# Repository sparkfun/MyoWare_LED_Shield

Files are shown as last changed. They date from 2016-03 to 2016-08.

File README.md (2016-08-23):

MyoWare™ LED Shield
========================================

MyoWare™ LED Shield

[*MyoWare LED Shield (13688)*](https://www.sparkfun.com/products/13688)

The MyoWare™ LED Shield is designed to pair with the MyoWare™ Muscle Sensor. The 10 segment bar graph shows the magnitude of the measured signal.

Repository Contents
-------------------

* **/Hardware** - Eagle design files (.brd, .sch)

Documentation
--------------
* **[Hookup Guide](https://learn.sparkfun.com/tutorials/myoware-muscle-sensor-kit?_ga=1.172011619.1515819426.1457626448)** - Basic hookup guide for the MyoWare™ LED Shield.
* **[SparkFun Fritzing repo](https://github.com/sparkfun/Fritzing_Parts)** - Fritzing diagrams for SparkFun products.
* **[SparkFun 3D Model repo](https://github.com/sparkfun/3D_Models)** - 3D models of SparkFun products.

License Information
-------------------

This product is _**open source**_!

Please review the LICENSE.md file for license information.

If you have any questions or concerns on licensing, please contact techsupport@sparkfun.com.

Distributed as-is; no warranty is given.

- Your friends at SparkFun.

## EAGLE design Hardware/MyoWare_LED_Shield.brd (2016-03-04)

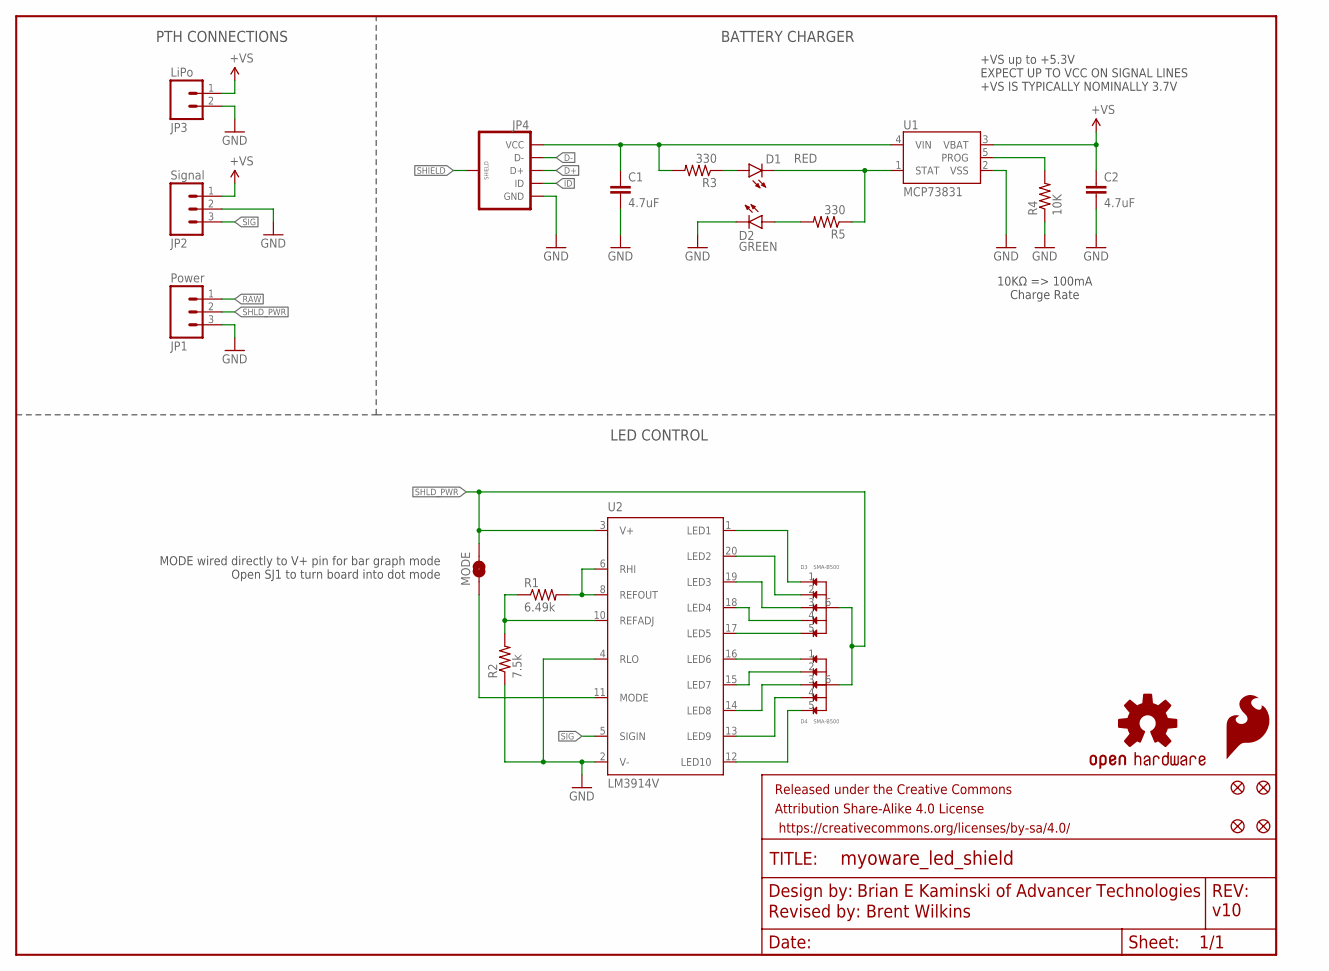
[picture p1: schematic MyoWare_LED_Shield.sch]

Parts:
C1, C2: 4.7uF; 0603-CAP
D1: RED; LED-0603
D2: GREEN; LED-0603
D3, D4: SMA-B500; LED_BAR_SMD
FID1, FID2, FID3, FID4: FIDUCIAL1X2; FIDUCIAL-1X2
FRAME1: FRAME-LETTER; CREATIVE_COMMONS
JP1: Power; 1X03_NO_SILK
JP2: Signal; 1X03_NO_SILK
JP3: LiPo; 1X02_NO_SILK
JP4: USB_MICROB_PLUGCONN-11752; USB-B-MICRO-SMD_V03
LOGO1: SFE_LOGO_FLAME.1_INCH; SFE_LOGO_FLAME_.1
LOGO2: OSHW-LOGOS; OSHW-LOGO-S
MODE: JUMPER-PAD-2-NC_BY_TRACE; PAD-JUMPER-2-NC_BY_TRACE_YES_SILK
R1: 6.49k; R0603
R2: 7.5k; R0603
R3, R5: 330; 0603-RES
R4: 10K; 0603-RES
U1: MCP73831; SOT23-5
U2: LM3914V; PLCC20S

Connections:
+VS: C2.1, JP2.1, JP3.1, U1.3 (VBAT)
D+: JP4.D+
D-: JP4.D-
GND: C1.2, C2.2, D2.C, JP1.3, JP2.2, JP3.2, JP4.GND, R2.1, R4.1, U1.2 (VSS), U2.2 (V-), U2.4 (RLO)
ID: JP4.ID
unnamed: D3.1, U2.1 (LED1)
unnamed: D3.2, U2.20 (LED2)
unnamed: D3.5, U2.17 (LED5)
unnamed: D3.3, U2.19 (LED3)
unnamed: D4.1, U2.16 (LED6)
unnamed: MODE.1, U2.11 (MODE)
unnamed: D3.4, U2.18 (LED4)
unnamed: D2.A, R5.2
unnamed: D1.A, R3.1
unnamed: D4.2, U2.15 (LED7)
unnamed: D4.3, U2.14 (LED8)
unnamed: D4.4, U2.13 (LED9)
unnamed: D4.5, U2.12 (LED10)
unnamed: D1.C, R5.1, U1.1 (STAT)
unnamed: R4.2, U1.5 (PROG)
unnamed: R1.1, R2.2, U2.10 (REFADJ)
unnamed: R1.2, U2.6 (RHI), U2.8 (REFOUT)
RAW: JP1.1
SHIELD: JP4.SHIELD1 (SHIELD), JP4.SHIELD2 (SHIELD), JP4.SHIELD3 (SHIELD)
SHLD_PWR: D3.6, D4.6, JP1.2, MODE.2, U2.3 (V+)
SIG: JP2.3, U2.5 (SIGIN)
VBUS: C1.1, JP4.VBUS (VCC), R3.2, U1.4 (VIN)

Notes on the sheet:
Brian E Kaminski of Advancer Technologies
Revised by: Brent Wilkins
v10
+VS up to +5.3V EXPECT UP TO VCC ON SIGNAL LINES +VS IS TYPICALLY NOMINALLY 3.7V
MODE wired directly to V+ pin for bar graph mode Open SJ1 to turn board into dot mode
PTH CONNECTIONS
BATTERY CHARGER
LED CONTROL
10KΩ => 100mA Charge Rate

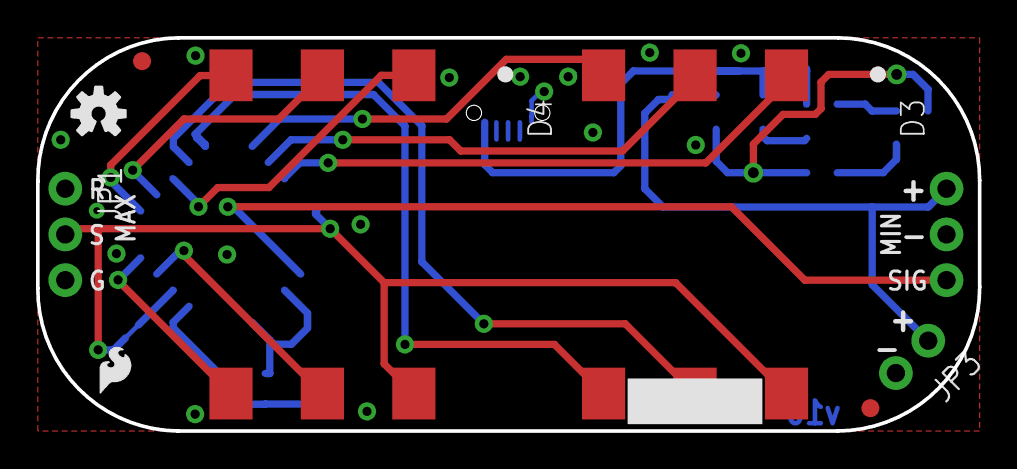
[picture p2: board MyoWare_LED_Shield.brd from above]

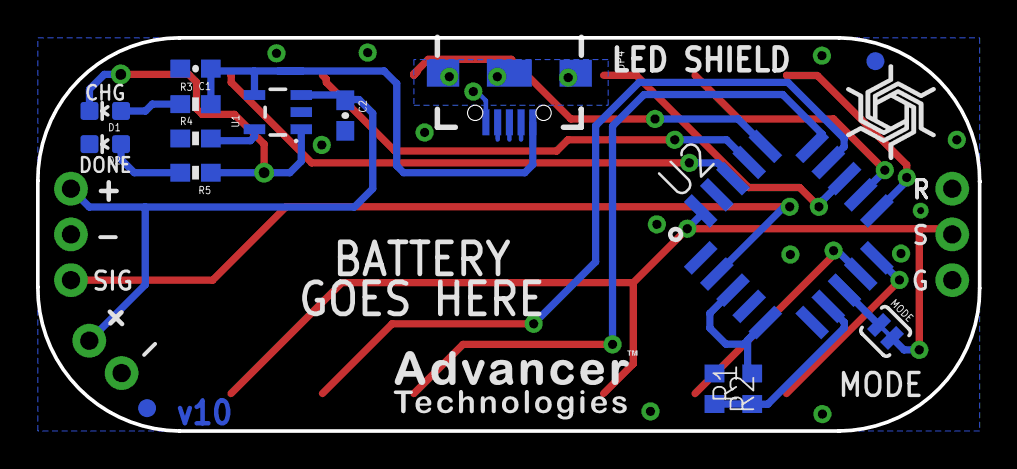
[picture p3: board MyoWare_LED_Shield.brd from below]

Board: 2 copper layers, 52.3 x 21.8 mm, 27 parts (17 on the bottom side), 23 nets.

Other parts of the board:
U$6: ADVANCER_LOGO
U$9: SPIRAL_LOGO_60%

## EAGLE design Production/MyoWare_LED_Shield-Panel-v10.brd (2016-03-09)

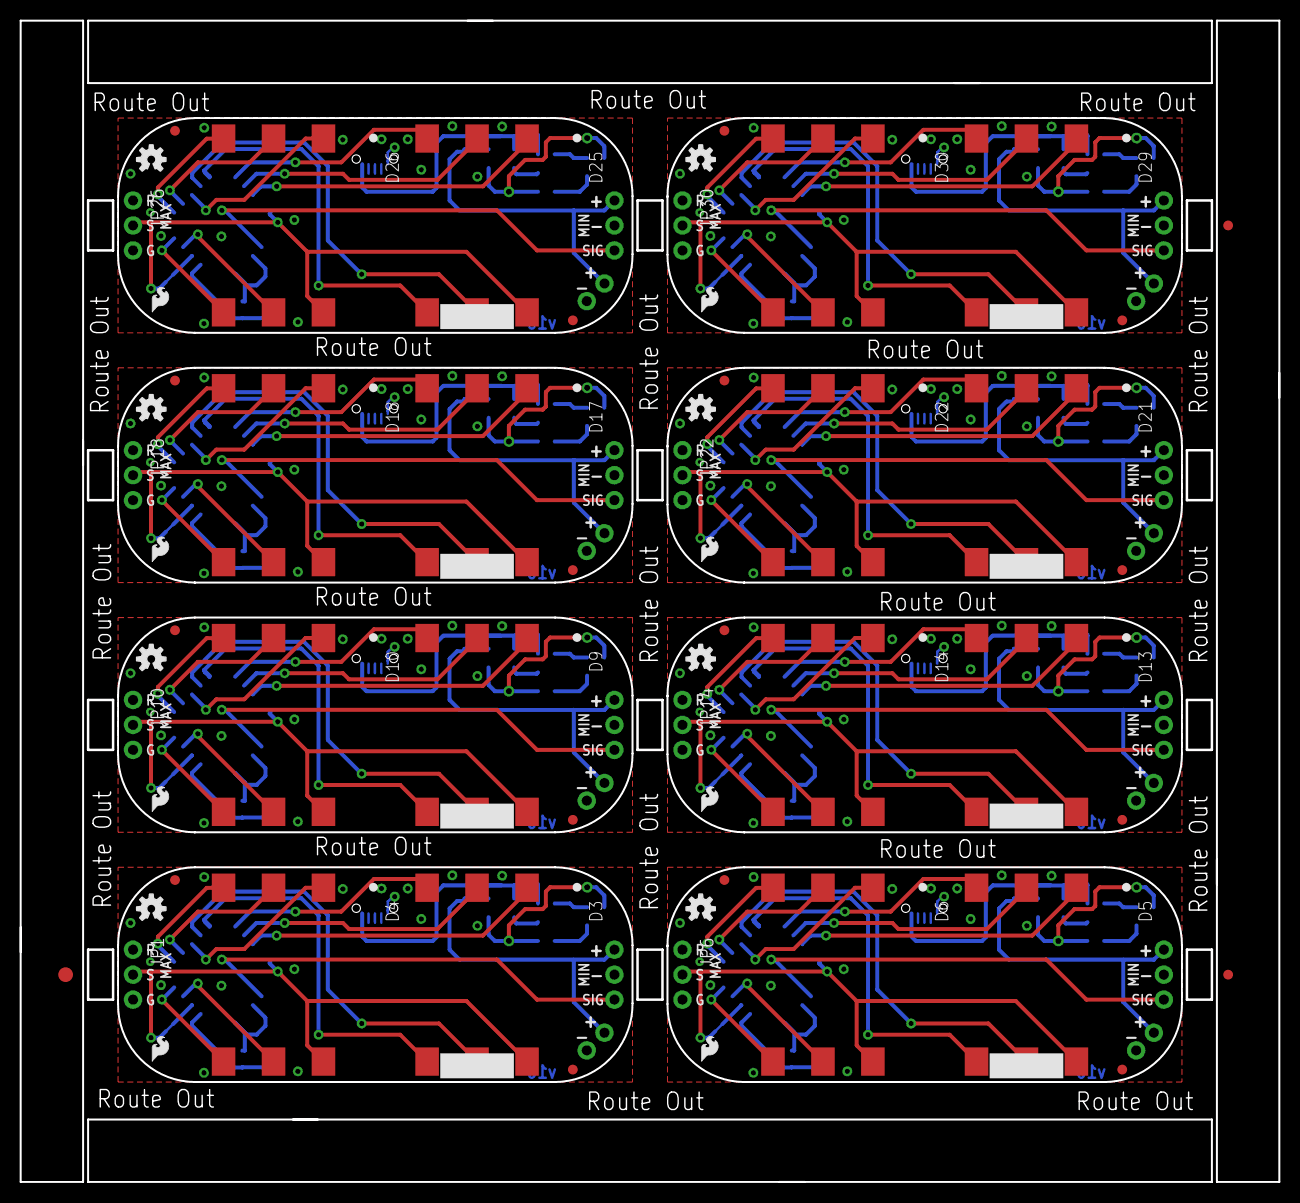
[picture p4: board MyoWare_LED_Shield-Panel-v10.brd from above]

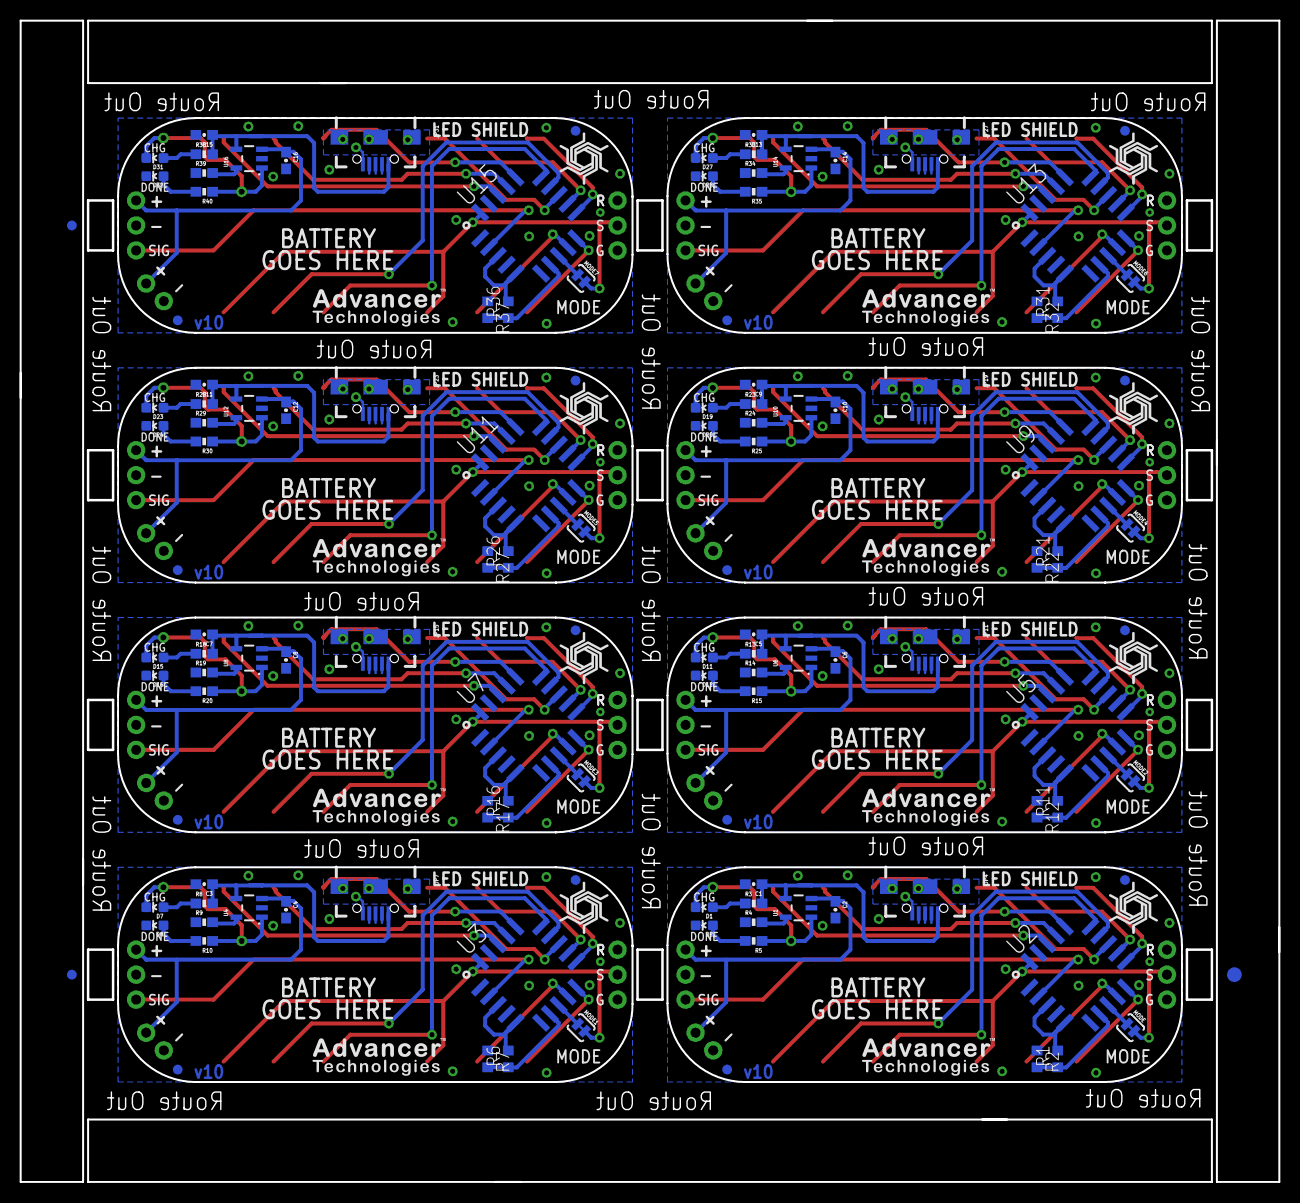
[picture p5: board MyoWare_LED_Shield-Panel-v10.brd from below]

Board: 2 copper layers, 128.0 x 118.1 mm, 214 parts (139 on the bottom side), 184 nets.

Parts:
C1, C2, C3, C4, C5, C6, C7, C8, C9, C10, C11, C12, C13, C14, C15, C16: 4.7uF; 0603-CAP
D1, D7, D11, D15, D19, D23, D27, D31: RED; LED-0603
D2, D8, D12, D16, D20, D24, D28, D32: GREEN; LED-0603
D3, D4, D5, D6, D9, D10, D13, D14, D17, D18, D21, D22, D25, D26, D29, D30: SMA-B500; LED_BAR_SMD
E$1, E$4: FIDUCIAL-1.5X3
E$2, E$3, E$5, E$6: FIDUCIAL-1X2
FID1, FID2, FID3, FID4, FID5, FID6, FID7, FID8, FID9, FID10, FID11, FID12, FID13, FID14, FID15, FID16, FID17, FID18, FID19, FID20, FID21, FID22, FID23, FID24, FID25, FID26, FID27, FID28, FID29, FID30, FID31, FID32: FIDUCIAL1X2; FIDUCIAL-1X2
JP1, JP6, JP10, JP14, JP18, JP22, JP26, JP30: Power; 1X03_NO_SILK
JP2, JP5, JP9, JP13, JP17, JP21, JP25, JP29: Signal; 1X03_NO_SILK
JP3, JP8, JP12, JP16, JP20, JP24, JP28, JP32: LiPo; 1X02_NO_SILK
JP4, JP7, JP11, JP15, JP19, JP23, JP27, JP31: USB-B-MICRO-SMD_V03
LOGO1, LOGO3, LOGO5, LOGO7, LOGO9, LOGO11, LOGO13, LOGO15: SFE_LOGO_FLAME.1_INCH; SFE_LOGO_FLAME_.1
LOGO2, LOGO4, LOGO6, LOGO8, LOGO10, LOGO12, LOGO14, LOGO16: OSHW-LOGOS; OSHW-LOGO-S
MODE, MODE1, MODE2, MODE3, MODE4, MODE5, MODE6, MODE7: JUMPER-PAD-2-NC_BY_TRACE; PAD-JUMPER-2-NC_BY_TRACE_YES_SILK
R1, R6, R11, R16, R21, R26, R31, R36: 6.49k; R0603
R2, R7, R12, R17, R22, R27, R32, R37: 7.5k; R0603
R3, R5, R8, R10, R13, R15, R18, R20, R23, R25, R28, R30, R33, R35, R38, R40: 330; 0603-RES
R4, R9, R14, R19, R24, R29, R34, R39: 10K; 0603-RES
U1, U4, U6, U8, U10, U12, U14, U16: MCP73831; SOT23-5
U2, U3, U5, U7, U9, U11, U13, U15: LM3914V; PLCC20S
U$1, U$3, U$5, U$8, U$9, U$11, U$13, U$15: SPIRAL_LOGO_60%
U$2, U$4, U$6, U$7, U$10, U$12, U$14, U$16: ADVANCER_LOGO

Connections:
+VS: C2.1, JP2.1, JP3.1, U1.3
+VS1: C4.1, JP5.1, JP8.1, U4.3
+VS2: C6.1, JP9.1, JP12.1, U6.3
+VS3: C8.1, JP13.1, JP16.1, U8.3
+VS4: C10.1, JP17.1, JP20.1, U10.3
+VS5: C12.1, JP21.1, JP24.1, U12.3
+VS6: C14.1, JP25.1, JP28.1, U14.3
+VS7: C16.1, JP29.1, JP32.1, U16.3
GND: C1.2, C2.2, D2.C, JP1.3, JP2.2, JP3.2, JP4.GND, R2.1, R4.1, U1.2, U2.2, U2.4
GND1: C3.2, C4.2, D8.C, JP5.2, JP6.3, JP7.GND, JP8.2, R7.1, R9.1, U3.2, U3.4, U4.2
GND2: C5.2, C6.2, D12.C, JP9.2, JP10.3, JP11.GND, JP12.2, R12.1, R14.1, U5.2, U5.4, U6.2
GND3: C7.2, C8.2, D16.C, JP13.2, JP14.3, JP15.GND, JP16.2, R17.1, R19.1, U7.2, U7.4, U8.2
GND4: C9.2, C10.2, D20.C, JP17.2, JP18.3, JP19.GND, JP20.2, R22.1, R24.1, U9.2, U9.4, U10.2
GND5: C11.2, C12.2, D24.C, JP21.2, JP22.3, JP23.GND, JP24.2, R27.1, R29.1, U11.2, U11.4, U12.2
GND6: C13.2, C14.2, D28.C, JP25.2, JP26.3, JP27.GND, JP28.2, R32.1, R34.1, U13.2, U13.4, U14.2
GND7: C15.2, C16.2, D32.C, JP29.2, JP30.3, JP31.GND, JP32.2, R37.1, R39.1, U15.2, U15.4, U16.2
unnamed: D3.1, U2.1
unnamed: D3.2, U2.20
unnamed: D3.5, U2.17
unnamed: D3.3, U2.19
unnamed: D4.1, U2.16
unnamed: MODE.1, U2.11
unnamed: D5.1, U3.1
unnamed: D3.4, U2.18
unnamed: D2.A, R5.2
unnamed: D1.A, R3.1
unnamed: D4.2, U2.15
unnamed: D4.3, U2.14
unnamed: D4.4, U2.13
unnamed: D4.5, U2.12
unnamed: D1.C, R5.1, U1.1
unnamed: D5.2, U3.20
unnamed: R4.2, U1.5
unnamed: D5.3, U3.19
unnamed: R1.1, R2.2, U2.10
unnamed: R1.2, U2.6, U2.8
unnamed: D5.4, U3.18
unnamed: D6.2, U3.15
unnamed: D6.3, U3.14
unnamed: D6.4, U3.13
unnamed: D6.5, U3.12
unnamed: R6.1, R7.2, U3.10
unnamed: R6.2, U3.6, U3.8
unnamed: D5.5, U3.17
unnamed: D6.1, U3.16
unnamed: MODE1.1, U3.11
unnamed: D7.A, R8.1
unnamed: D7.C, R10.1, U4.1
unnamed: R9.2, U4.5
unnamed: D8.A, R10.2
unnamed: D9.1, U5.1
unnamed: D9.2, U5.20
unnamed: D9.3, U5.19
unnamed: D9.4, U5.18
unnamed: D10.2, U5.15
unnamed: D10.3, U5.14
unnamed: D10.4, U5.13
unnamed: D10.5, U5.12
unnamed: R11.1, R12.2, U5.10
unnamed: R11.2, U5.6, U5.8
unnamed: D9.5, U5.17
unnamed: D10.1, U5.16
unnamed: MODE2.1, U5.11
unnamed: D11.A, R13.1
unnamed: D11.C, R15.1, U6.1
unnamed: R14.2, U6.5
unnamed: D12.A, R15.2
unnamed: D13.1, U7.1
unnamed: D13.2, U7.20
unnamed: D13.3, U7.19
unnamed: D13.4, U7.18
unnamed: D14.2, U7.15
unnamed: D14.3, U7.14
unnamed: D14.4, U7.13
unnamed: D14.5, U7.12
unnamed: R16.1, R17.2, U7.10
unnamed: R16.2, U7.6, U7.8
unnamed: D13.5, U7.17
unnamed: D14.1, U7.16
unnamed: MODE3.1, U7.11
unnamed: D15.A, R18.1
unnamed: D15.C, R20.1, U8.1
unnamed: R19.2, U8.5
unnamed: D16.A, R20.2
unnamed: D17.1, U9.1
unnamed: D17.2, U9.20
unnamed: D17.3, U9.19
unnamed: D17.4, U9.18
unnamed: D18.2, U9.15
unnamed: D18.3, U9.14
unnamed: D18.4, U9.13
unnamed: D18.5, U9.12
unnamed: R21.1, R22.2, U9.10
unnamed: R21.2, U9.6, U9.8
unnamed: D17.5, U9.17
unnamed: D18.1, U9.16
unnamed: MODE4.1, U9.11
unnamed: D19.A, R23.1
unnamed: D19.C, R25.1, U10.1
unnamed: R24.2, U10.5
unnamed: D20.A, R25.2
unnamed: D21.1, U11.1
unnamed: D21.2, U11.20
unnamed: D21.3, U11.19
unnamed: D21.4, U11.18
unnamed: D22.2, U11.15
unnamed: D22.3, U11.14
unnamed: D22.4, U11.13
unnamed: D22.5, U11.12
unnamed: R26.1, R27.2, U11.10
unnamed: R26.2, U11.6, U11.8
unnamed: D21.5, U11.17
unnamed: D22.1, U11.16
unnamed: MODE5.1, U11.11
unnamed: D23.A, R28.1
unnamed: D23.C, R30.1, U12.1
unnamed: R29.2, U12.5
unnamed: D24.A, R30.2
unnamed: D25.1, U13.1
unnamed: D25.2, U13.20
unnamed: D25.3, U13.19
unnamed: D25.4, U13.18
unnamed: D26.2, U13.15
unnamed: D26.3, U13.14
unnamed: D26.4, U13.13
unnamed: D26.5, U13.12
unnamed: R31.1, R32.2, U13.10
unnamed: R31.2, U13.6, U13.8
unnamed: D25.5, U13.17
unnamed: D26.1, U13.16
unnamed: MODE6.1, U13.11
unnamed: D27.A, R33.1
unnamed: D27.C, R35.1, U14.1
unnamed: R34.2, U14.5
unnamed: D28.A, R35.2
unnamed: D29.1, U15.1
unnamed: D29.2, U15.20
unnamed: D29.3, U15.19
unnamed: D29.4, U15.18
unnamed: D30.2, U15.15
unnamed: D30.3, U15.14
unnamed: D30.4, U15.13
unnamed: D30.5, U15.12
unnamed: R36.1, R37.2, U15.10
unnamed: R36.2, U15.6, U15.8
unnamed: D29.5, U15.17
unnamed: D30.1, U15.16
unnamed: MODE7.1, U15.11
unnamed: D31.A, R38.1
unnamed: D31.C, R40.1, U16.1
unnamed: R39.2, U16.5
unnamed: D32.A, R40.2
SHIELD: JP4.SHIELD1, JP4.SHIELD2, JP4.SHIELD3
SHIELD1: JP7.SHIELD1, JP7.SHIELD2, JP7.SHIELD3
SHIELD2: JP11.SHIELD1, JP11.SHIELD2, JP11.SHIELD3
SHIELD3: JP15.SHIELD1, JP15.SHIELD2, JP15.SHIELD3
SHIELD4: JP19.SHIELD1, JP19.SHIELD2, JP19.SHIELD3
SHIELD5: JP23.SHIELD1, JP23.SHIELD2, JP23.SHIELD3
SHIELD6: JP27.SHIELD1, JP27.SHIELD2, JP27.SHIELD3
SHIELD7: JP31.SHIELD1, JP31.SHIELD2, JP31.SHIELD3
SHLD_PWR: D3.6, D4.6, JP1.2, MODE.2, U2.3
SHLD_PWR1: D5.6, D6.6, JP6.2, MODE1.2, U3.3
SHLD_PWR2: D9.6, D10.6, JP10.2, MODE2.2, U5.3
SHLD_PWR3: D13.6, D14.6, JP14.2, MODE3.2, U7.3
SHLD_PWR4: D17.6, D18.6, JP18.2, MODE4.2, U9.3
SHLD_PWR5: D21.6, D22.6, JP22.2, MODE5.2, U11.3
SHLD_PWR6: D25.6, D26.6, JP26.2, MODE6.2, U13.3
SHLD_PWR7: D29.6, D30.6, JP30.2, MODE7.2, U15.3
SIG: JP2.3, U2.5
SIG1: JP5.3, U3.5
SIG2: JP9.3, U5.5
SIG3: JP13.3, U7.5
SIG4: JP17.3, U9.5
SIG5: JP21.3, U11.5
SIG6: JP25.3, U13.5
SIG7: JP29.3, U15.5
VBUS: C1.1, JP4.VBUS, R3.2, U1.4
VBUS1: C3.1, JP7.VBUS, R8.2, U4.4
VBUS2: C5.1, JP11.VBUS, R13.2, U6.4
VBUS3: C7.1, JP15.VBUS, R18.2, U8.4
VBUS4: C9.1, JP19.VBUS, R23.2, U10.4
VBUS5: C11.1, JP23.VBUS, R28.2, U12.4
VBUS6: C13.1, JP27.VBUS, R33.2, U14.4
VBUS7: C15.1, JP31.VBUS, R38.2, U16.4

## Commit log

2015-07-27 Added prod_id to LEDs
    [MyoWare_LED_Shield.brd, MyoWare_LED_Shield.sch]
2015-07-27 Cosmetic tweaks
    [MyoWare_LED_Shield.brd, MyoWare_LED_Shield.sch]
2015-11-16 Started move to LiPo based design
    [MyoWare_LED_Shield.brd, MyoWare_LED_Shield.sch]
2015-11-16 Design rules checked
    [MyoWare_LED_Shield.brd, MyoWare_LED_Shield.sch]
2015-11-16 Adjusted max +VS
    [MyoWare_LED_Shield.sch]
2015-11-16 Tweaks (mostly silk and info)
    [MyoWare_LED_Shield.brd, MyoWare_LED_Shield.sch]
2015-11-17 Moved the USB jack to board edge to prevent interference with part flair
    [MyoWare_LED_Shield.brd]
2016-03-02 Moved charge LEDs to back of board from easier manufacturing
    [MyoWare_LED_Shield.brd, MyoWare_LED_Shield.sch]
2016-03-03 Added cable header alignment in silk & minor weaks.
    [MyoWare_LED_Shield.brd, MyoWare_LED_Shield.sch]
2016-03-03 Improved micro-B DFM & fixed alignment silk
    [MyoWare_LED_Shield.brd, MyoWare_LED_Shield.sch]
2016-03-04 Resolved issue #8 and isuue #9
    [MyoWare_LED_Shield.brd, MyoWare_LED_Shield.sch]
2016-03-04 Change charge done LED to green
    [MyoWare_LED_Shield.brd, MyoWare_LED_Shield.sch]
2016-03-09 created panel v10
    [MyoWare_LED_Shield-Panel-v10.brd]

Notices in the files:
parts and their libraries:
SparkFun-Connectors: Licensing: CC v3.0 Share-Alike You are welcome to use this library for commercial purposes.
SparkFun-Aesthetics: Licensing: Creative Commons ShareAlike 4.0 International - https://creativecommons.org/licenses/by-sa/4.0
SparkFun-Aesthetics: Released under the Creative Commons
